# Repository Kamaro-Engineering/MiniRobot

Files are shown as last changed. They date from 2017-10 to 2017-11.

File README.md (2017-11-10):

# MiniRobot
All construction files for a mini robot platform.

This mini robot platform was developed as an entry project for the [KAMARO](https://kamaro-engineering.de/) student group. 

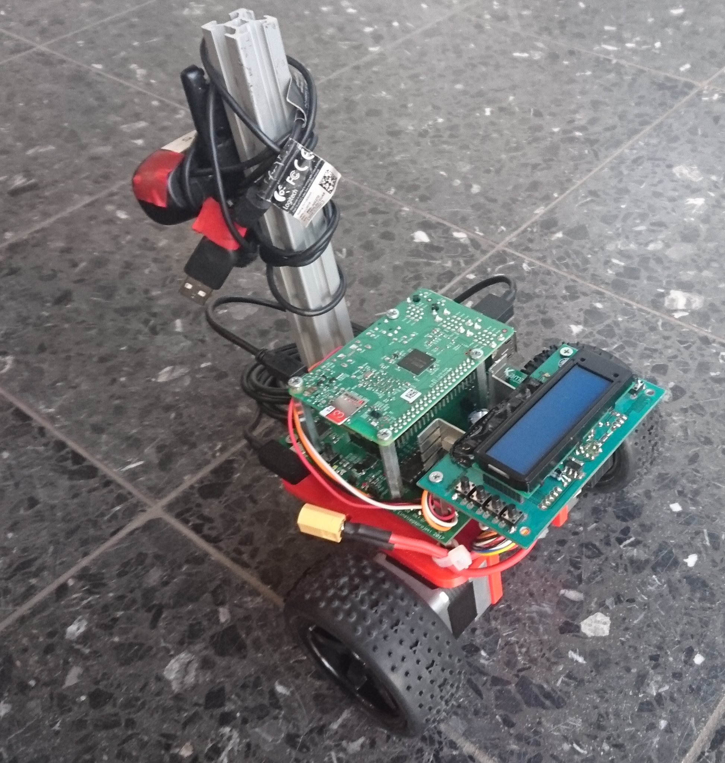
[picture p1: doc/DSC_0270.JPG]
robot

(The display is not part of this project but by chance the drill holes fitted)

# CAD / Mechanics

At the moment we only provide the stl file of the robot base. On request I can provide the Free Cad file too. 

For assembly you need to 3D print the base. We did this on an ultimaker 2+.
The stepper motors we used are standard NEMA12 steppers in combination with standard rc car wheels. (Diameter will be added after I measured it)

# Circuit / Layout

The circuit schematics and layouts were done in the EAGLE layout software. The layout is partly in THT and SMD. All ICs apart from the FTDI (which is only available in SMD) are in THT, the resistors and capacitors are mostly in SMD (0805). As they are in 0805 also beginners will be able to solder them with a bit of training. (It sounds hardware that it is ;) 

The only part you have to adjust are the resistor values for the current limit of the L297. Adapt them to your maximum allowed motor current. (R7,R8 and R3,R4)

The four drill holes in the middle can be used in order to mount a raspberry pi 2 (or 3).

# Software

We provide a fully functional firmware for the Atmega48 (or 88). See the readme in the source subfolder for the serial communication protocol. (It's really simple, just 4 bytes). In most case the only thing you might have to adapt are the constants of the odomotry which is calculated with the amount of steps done by the steppers. For example in case you use a stepper with smaller steps or larger wheels you will have to adapt these constants.

See the [software readme](source/README.md)!

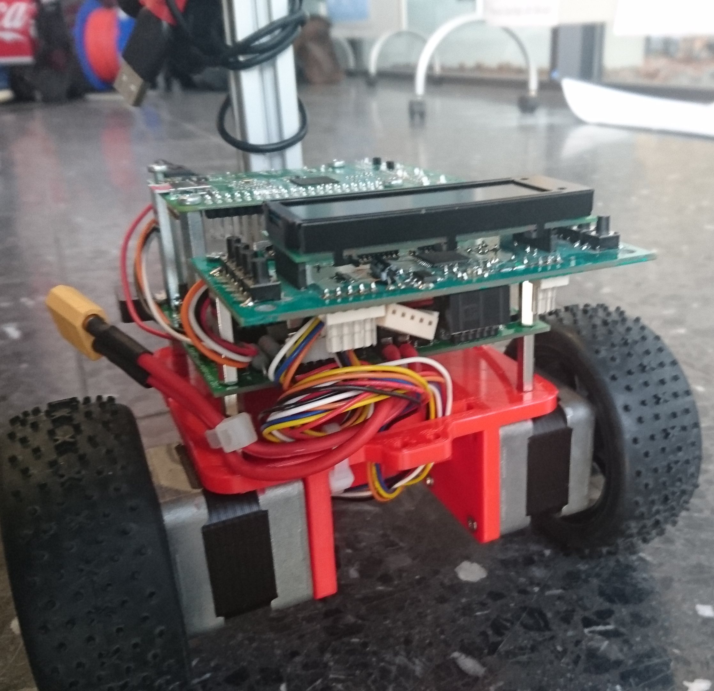
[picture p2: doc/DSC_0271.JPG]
robot1


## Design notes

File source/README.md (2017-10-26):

# MiniRobot - Embeddedcode

This code is written for an Atmega48 (or 88) in C. It can be compiled with avr-gcc.
On Linux you need the following packages:

```
sudo apt install gcc-avr avr-libc  avrdude make
```
In order to build the code, open a terminal, step into the src folder and type `make`.
Via `make program` you can program the controller with a avr-isp mk II programmer. For other programmers have a look at the makefile.

## Communicationprotocol

The robot supports the following commands via a virtual comport. (500000 BAUD)

Format:
STARTBYTE | Command | Highbyte-Data | Lowbyte-Data |

The STARTBYTE matches the ASCII '#'

Commands that can be sent to the robot.

| Command | Data | Description |
| --- | --- | --- |
| 0x01 | enable | Enables/Disables motors  |
| 0x02 | speed left | Set velocity or speed for the left side  (signed integer!)|
| 0x03 | speed right | Set velocity or speed for the right side (signed integer!) |
| 0x04 | led number | Enable LED x |
| 0x05 | led number | Disable LED x |
| 0x06 | PWM | Set pwm freq of fan  |
| 0x07 | PWM | Set pwm freq of external pin | 
| 0x08 | enable | Enable/Disables sending of ultrasonic sensor  data |
| 0x09 | enable | Enable/Disables sending of battery voltage |
| 0x0A | enable | Enable/Disables sending of motor currents |
| 0x0B | enable | Enable/Disables sending of Encoder right and left | 
| 0x0C | enable | Enable/Disables sending of Odometry x,y and phi | 

Data that will be sent back from the robot.

| Command | Data | Description |
| --- | --- | --- |
| 0x80 | ultra sonic sensor distance in cm | ultra sonic sensor |
| 0x81 | Battery voltage in mV |  |
| 0x82 | Motor current left in mA | |
| 0x83 | Motor current right in mA |  |
| 0x84 | Taster pressed |  |
| 0x85 | Encoder right |  |
| 0x86 | Encoder left |  |
| 0x87 | Odometry x |  |
| 0x88 | Odometry y |  |
| 0x89 | Odometry phi |  |

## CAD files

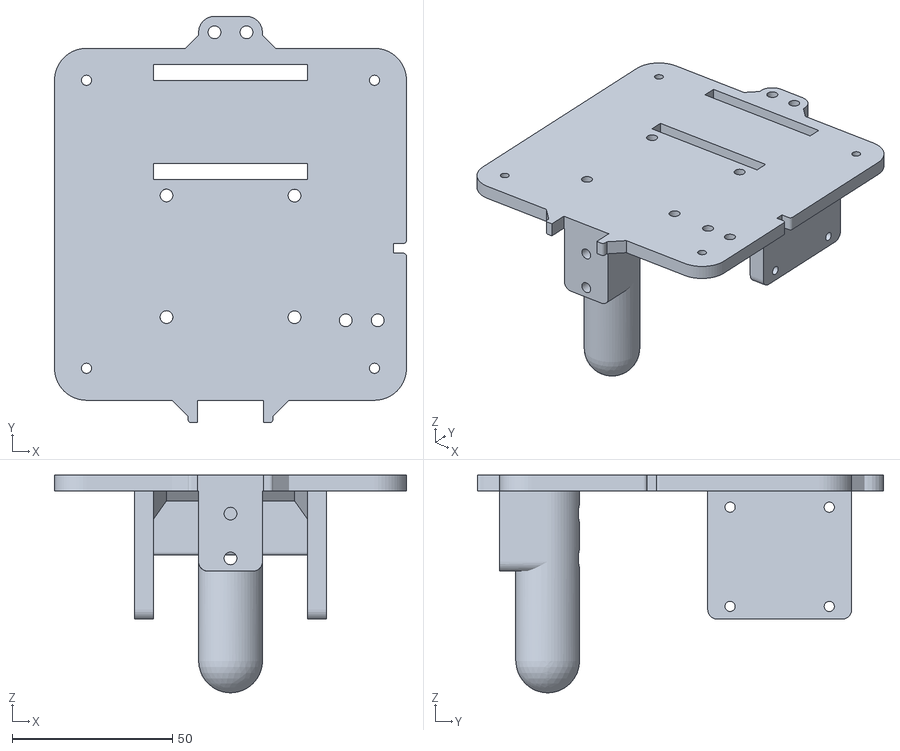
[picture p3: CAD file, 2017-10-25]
cad/einstiegsrobot.stl
110.0 x 127.0 x 68.0

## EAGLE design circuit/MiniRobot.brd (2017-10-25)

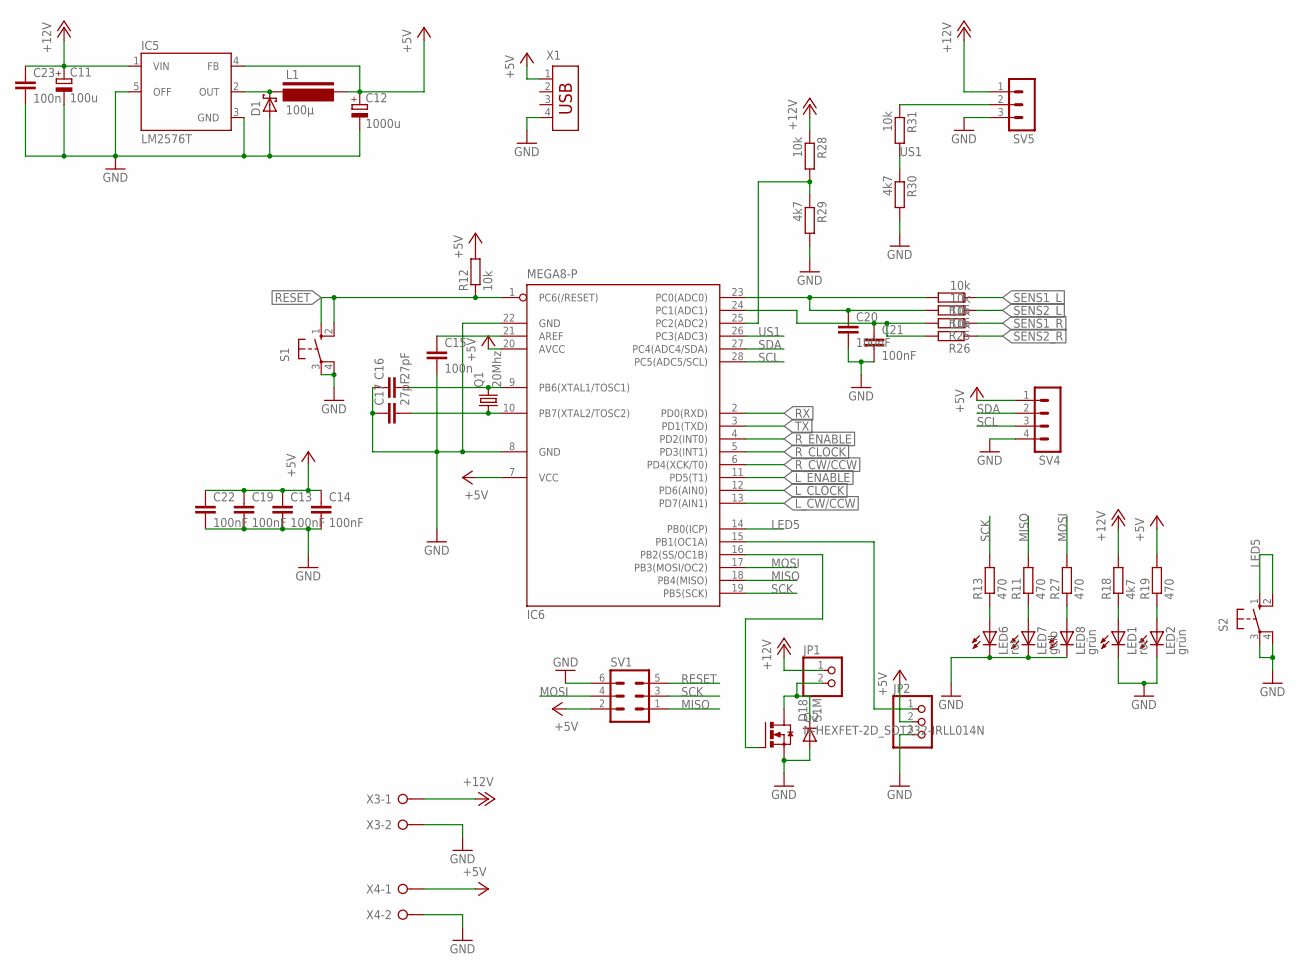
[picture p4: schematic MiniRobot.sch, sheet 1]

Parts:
C11: 100u; E5-10,5
C12: 1000u; E5-10,5
C13, C14, C19, C20, C21, C22: 100nF; C0805
C15, C23: 100n; C0805
C16, C17: 27pF; C0805
D1: SCHOTTKY-DIODEF126Z12; F126Z12
D18: S1M; SMA
IC5: LM2576T; TO220-5
IC6: MEGA8-P; DIL28-3
JP1: PINHD-1X2; 1X02
JP2: PINHD-1X3; 1X03
L1: 100µ; PISR
LED1, LED6: rot; CHIP-LED0805
LED2, LED8: grün; CHIP-LED0805
LED7: gelb; CHIP-LED0805
Q1: 20Mhz; CSM-7X-DU
Q2: N-HEXFET-2D_SOT232-IRLL014N; SOT223
R11, R13, R19: 470; M0805
R12, R15, R31: 10k; R0805
R16, R25, R26, R28: 10k; M0805
R18, R30: 4k7; R0805
R27: 470; R0805
R29: 4k7; M0805
S1, S2: 10-XX; B3F-10XX
SV1: ML6
SV4: MA04-1
SV5: MA03-1
X1: USB-787616; USB
X3, X4: W237-02P; W237-132

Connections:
+5V: C12.+, C13.1, C14.1, C19.1, C22.1, IC5.4 (FB), IC6.7 (VCC), IC6.20 (AVCC), JP2.2, L1.P$2, R12.2, R19.2, SV1.2, SV4.1, X1.1, X4.1; also elsewhere on the board
+12V: C11.+, C23.1, IC5.1 (VIN), JP1.1, R18.2, R28.1, SV5.1, X3.1; also elsewhere on the board
GND: C11.-, C12.-, C13.2, C14.2, C15.2, C16.1, C17.1, C19.2, C20.2, C21.2, C22.2, C23.2, D1.A, D18.A, IC5.3 (GND), IC5.5 (OFF), IC6.8 (GND), IC6.22 (GND), JP2.3, LED1.C, LED2.C, LED6.C, LED7.C, LED8.C, Q2.3 (S), R29.2, R30.2, S1.3, S1.4 (P1), S2.3, S2.4 (P1), SV1.6, SV4.4, SV5.3, X1.4, X3.2, X4.2; also elsewhere on the board
LED5: IC6.14 (PB0(ICP)), S2.1 (S), S2.2 (S1)
L_CLOCK: IC6.12 (PD6(AIN0)); also elsewhere on the board
L_CW/CCW: IC6.13 (PD7(AIN1)); also elsewhere on the board
L_ENABLE: IC6.11 (PD5(T1)); also elsewhere on the board
MISO: IC6.18 (PB4(MISO)), R11.2, SV1.1
MOSI: IC6.17 (PB3(MOSI/OC2)), R27.2, SV1.4
unnamed: LED8.A, R27.1
unnamed: C21.1, IC6.24 (PC1(ADC1)), R25.2, R26.2
unnamed: C15.1, IC6.21 (AREF)
unnamed: C16.2, IC6.9 (PB6(XTAL1/TOSC1)), Q1.2
unnamed: D1.C, IC5.2 (OUT), L1.P$1
unnamed: IC6.25 (PC2(ADC2)), R28.2, R29.1
unnamed: C17.2, IC6.10 (PB7(XTAL2/TOSC2)), Q1.1
unnamed: C20.1, IC6.23 (PC0(ADC0)), R15.2, R16.2
unnamed: LED1.A, R18.1
unnamed: LED2.A, R19.1
unnamed: LED6.A, R13.1
unnamed: LED7.A, R11.1
unnamed: R31.1, SV5.2
unnamed: D18.C, JP1.2, Q2.2 (D), Q2.4 (D)
unnamed: IC6.16 (PB2(SS/OC1B)), Q2.1 (G)
unnamed: IC6.15 (PB1(OC1A)), JP2.1
RESET: IC6.1 (PC6(/RESET)), R12.1, S1.1 (S), S1.2 (S1), SV1.5; also elsewhere on the board
RX: IC6.2 (PD0(RXD)); also elsewhere on the board
R_CLOCK: IC6.5 (PD3(INT1)); also elsewhere on the board
R_CW/CCW: IC6.6 (PD4(XCK/T0)); also elsewhere on the board
R_ENABLE: IC6.4 (PD2(INT0)); also elsewhere on the board
SCK: IC6.19 (PB5(SCK)), R13.2, SV1.3
SCL: IC6.28 (PC5(ADC5/SCL)), SV4.3
SDA: IC6.27 (PC4(ADC4/SDA)), SV4.2
SENS1_L: R15.1; also elsewhere on the board
SENS1_R: R25.1; also elsewhere on the board
SENS2_L: R16.1; also elsewhere on the board
SENS2_R: R26.1; also elsewhere on the board
TX: IC6.3 (PD1(TXD)); also elsewhere on the board
US1: IC6.26 (PC3(ADC3)), R30.1, R31.2

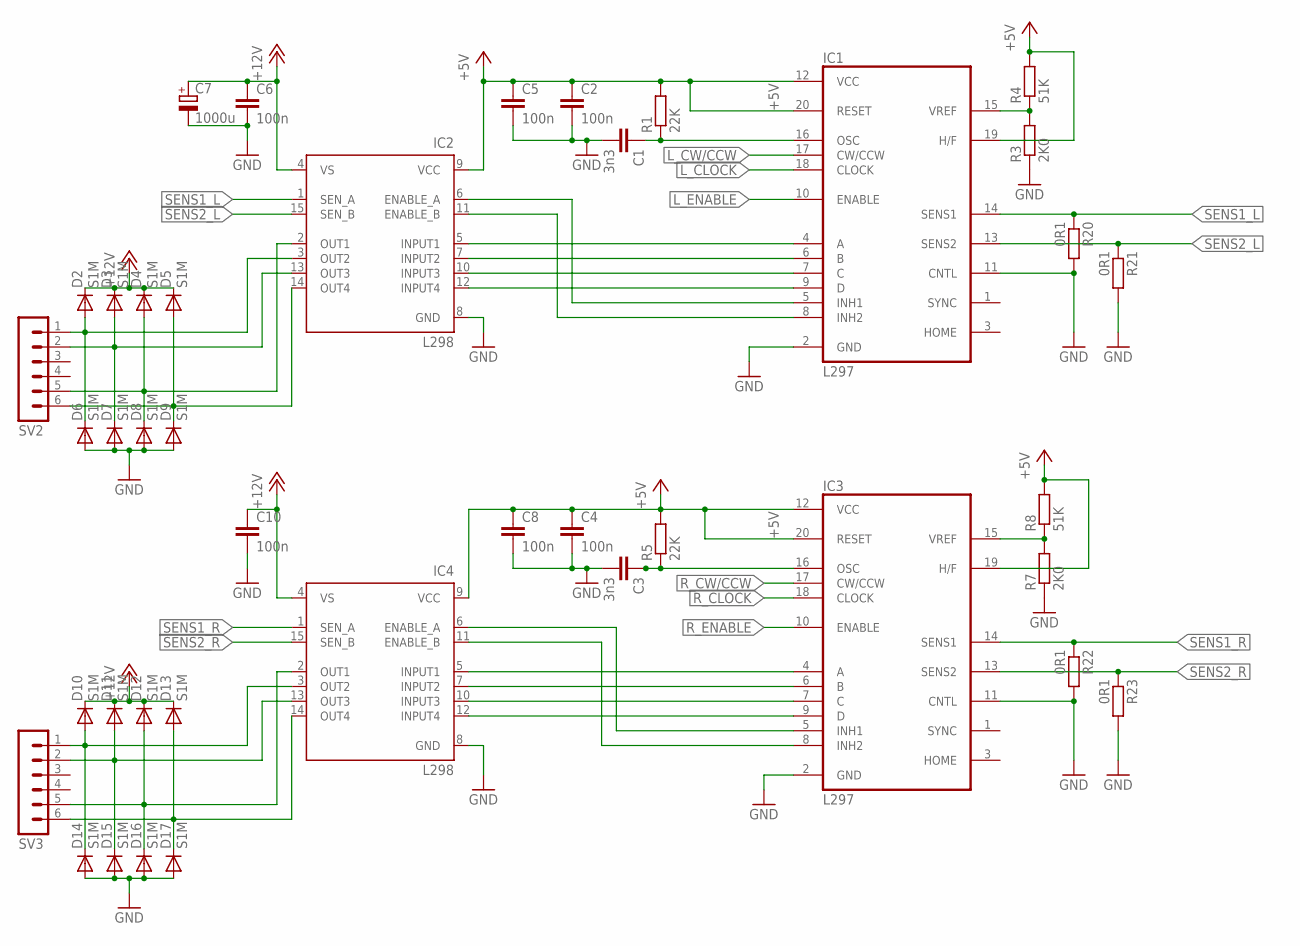
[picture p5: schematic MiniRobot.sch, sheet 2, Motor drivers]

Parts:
C1, C3: 3n3; C0805
C2, C4, C5, C6, C8, C10: 100n; C0805
C7: 1000u; E5-10,5
D2, D3, D4, D5, D6, D7, D8, D9, D10, D11, D12, D13, D14, D15, D16, D17: S1M; SMA
IC1, IC3: L297; DIL20
IC2, IC4: L298; MULTIWATT-15
R1, R5: 22K; R0805
R3, R7: 2K0; R0805
R4, R8: 51K; R0805
R20, R21, R22, R23: 0R1; P0613/15
SV2, SV3: MA06-1

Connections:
+5V: C2.1, C4.1, C5.1, C8.1, IC1.12 (VCC), IC1.19 (H/F), IC1.20 (RESET), IC2.9 (VCC), IC3.12 (VCC), IC3.19 (H/F), IC3.20 (RESET), IC4.9 (VCC), R1.2, R4.2, R5.2, R8.2; also elsewhere on the board
+12V: C6.1, C7.+, C10.1, D2.C, D3.C, D4.C, D5.C, D10.C, D11.C, D12.C, D13.C, IC2.4 (VS), IC4.4 (VS); also elsewhere on the board
GND: C1.2, C2.2, C3.2, C4.2, C5.2, C6.2, C7.-, C8.2, C10.2, D6.A, D7.A, D8.A, D9.A, D14.A, D15.A, D16.A, D17.A, IC1.2 (GND), IC1.11 (CNTL), IC2.8 (GND), IC3.2 (GND), IC3.11 (CNTL), IC4.8 (GND), R3.1, R7.1, R20.2, R21.2, R22.2, R23.2; also elsewhere on the board
L_CLOCK: IC1.18 (CLOCK); also elsewhere on the board
L_CW/CCW: IC1.17 (CW/CCW); also elsewhere on the board
L_ENABLE: IC1.10 (ENABLE); also elsewhere on the board
unnamed: C1.1, IC1.16 (OSC), R1.1
unnamed: IC1.4 (A), IC2.5 (INPUT1)
unnamed: IC1.6 (B), IC2.7 (INPUT2)
unnamed: IC1.7 (C), IC2.10 (INPUT3)
unnamed: C3.1, IC3.16 (OSC), R5.1
unnamed: IC3.6 (B), IC4.7 (INPUT2)
unnamed: IC1.9 (D), IC2.12 (INPUT4)
unnamed: IC1.5 (INH1), IC2.6 (ENABLE_A)
unnamed: IC1.15 (VREF), R3.2, R4.1
unnamed: D4.A, D8.C, IC2.2 (OUT1), SV2.5
unnamed: IC3.4 (A), IC4.5 (INPUT1)
unnamed: IC3.7 (C), IC4.10 (INPUT3)
unnamed: IC3.9 (D), IC4.12 (INPUT4)
unnamed: IC3.15 (VREF), R7.2, R8.1
unnamed: IC3.5 (INH1), IC4.6 (ENABLE_A)
unnamed: IC1.8 (INH2), IC2.11 (ENABLE_B)
unnamed: D2.A, D6.C, IC2.3 (OUT2), SV2.1
unnamed: D3.A, D7.C, IC2.13 (OUT3), SV2.2
unnamed: D5.A, D9.C, IC2.14 (OUT4), SV2.6
unnamed: IC3.8 (INH2), IC4.11 (ENABLE_B)
unnamed: D10.A, D14.C, IC4.3 (OUT2), SV3.1
unnamed: D12.A, D16.C, IC4.2 (OUT1), SV3.5
unnamed: D13.A, D17.C, IC4.14 (OUT4), SV3.6
unnamed: D11.A, D15.C, IC4.13 (OUT3), SV3.2
R_CLOCK: IC3.18 (CLOCK); also elsewhere on the board
R_CW/CCW: IC3.17 (CW/CCW); also elsewhere on the board
R_ENABLE: IC3.10 (ENABLE); also elsewhere on the board
SENS1_L: IC1.14 (SENS1), IC2.1 (SEN_A), R20.1; also elsewhere on the board
SENS1_R: IC3.14 (SENS1), IC4.1 (SEN_A), R22.1; also elsewhere on the board
SENS2_L: IC1.13 (SENS2), IC2.15 (SEN_B), R21.1; also elsewhere on the board
SENS2_R: IC3.13 (SENS2), IC4.15 (SEN_B), R23.1; also elsewhere on the board

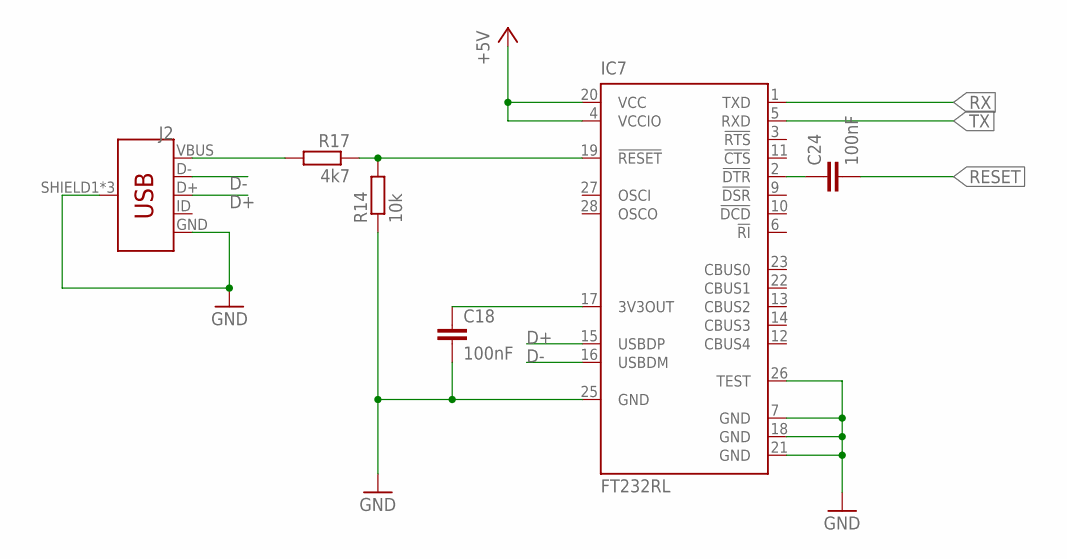
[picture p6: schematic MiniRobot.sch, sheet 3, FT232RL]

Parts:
C18, C24: 100nF; C0805
IC7: FT232RL; SSOP28
J2: USB_MICRO-B_FEMALE-SMT; USB-B-MICRO-SMD
R14: 10k; M0805
R17: 4k7; M0805

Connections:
+5V: IC7.4 (VCCIO), IC7.20 (VCC); also elsewhere on the board
D+: IC7.15 (USBDP), J2.D+
D-: IC7.16 (USBDM), J2.D-
GND: C18.2, IC7.7 (GND), IC7.18 (GND), IC7.21 (GND), IC7.25 (GND), IC7.26 (TEST), J2.GND, J2.SHIELD1 (SHIELD), J2.SHIELD2 (SHIELD), J2.SHIELD3 (SHIELD), R14.1; also elsewhere on the board
unnamed: J2.VBUS, R17.2
unnamed: IC7.19 (!RESET), R14.2, R17.1
unnamed: C18.1, IC7.17 (3V3OUT)
unnamed: C24.1, IC7.2 (!DTR)
RESET: C24.2; also elsewhere on the board
RX: IC7.1 (TXD); also elsewhere on the board
TX: IC7.5 (RXD); also elsewhere on the board

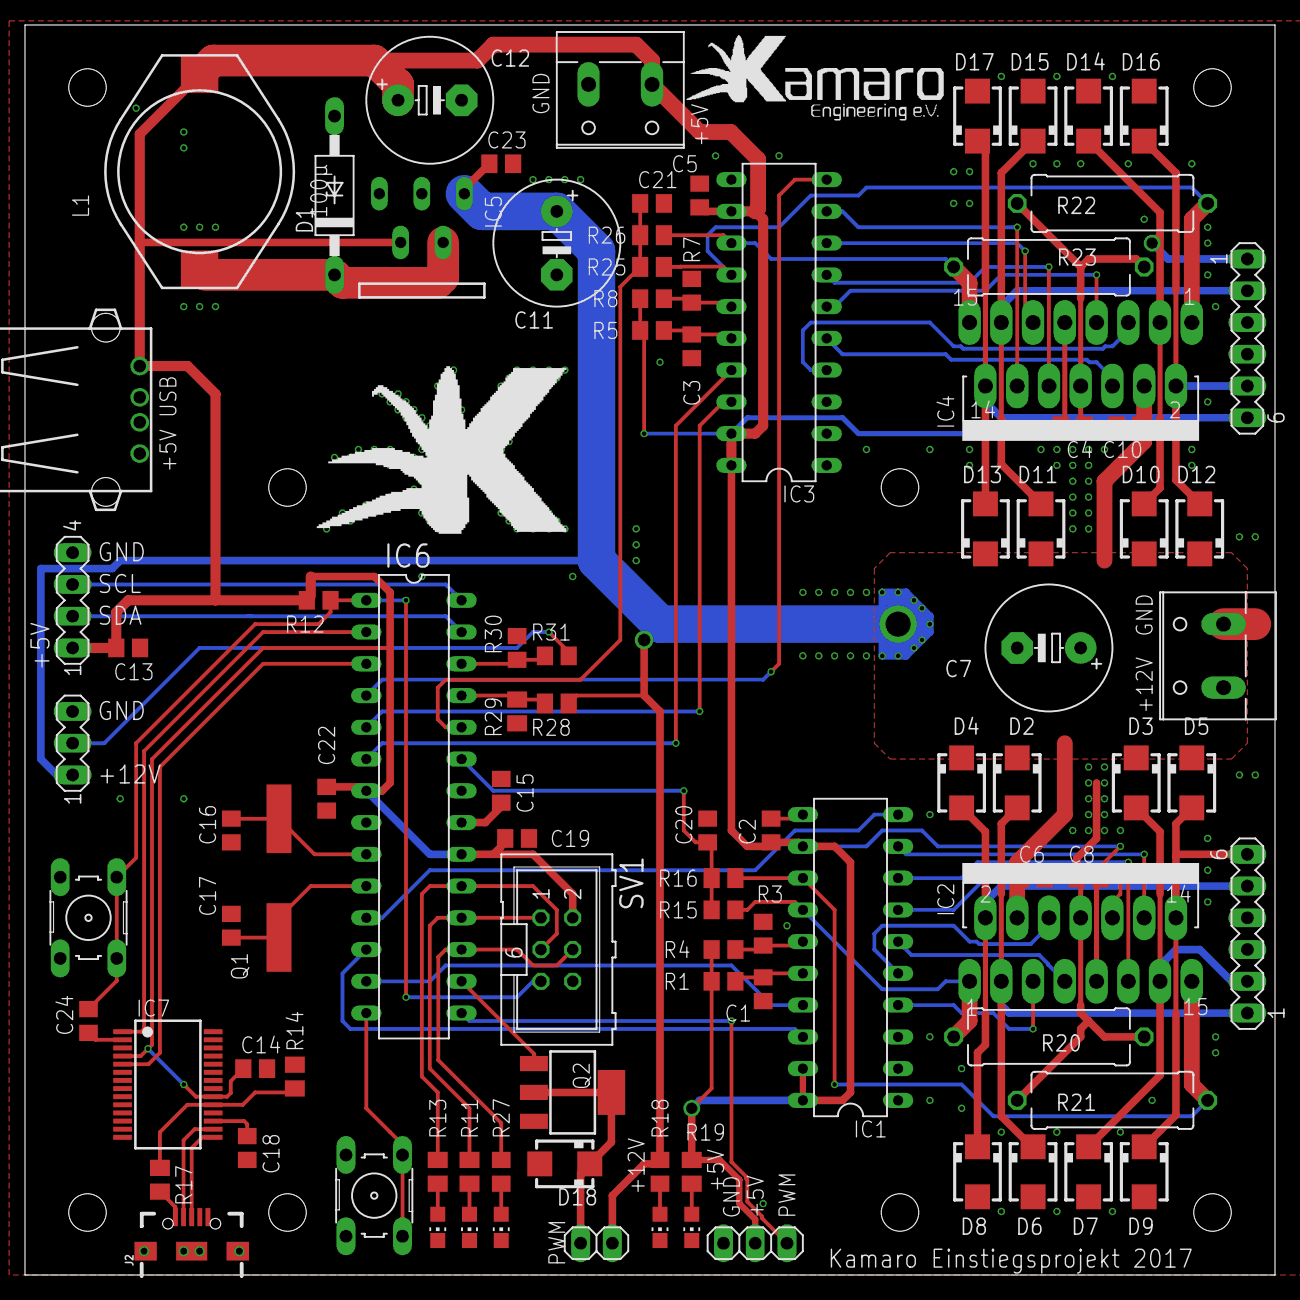
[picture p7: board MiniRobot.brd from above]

Board: 2 copper layers, 100.0 x 100.0 mm, 95 parts (0 on the bottom side), 69 nets.

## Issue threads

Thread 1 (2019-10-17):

Wrong Value for L297 sense resistors in schematic.

knicklux, 2019-10-17:
Wrong Value for L297 sense resistors in schematic.

The correct value according to the L297 datasheet and our measurements on the existing board is 0.5 Ohm. The value in the schematic is 0.1 Ohm.

firesurfer, 2019-10-18:
So einfach ist das nicht ;) Frag mal Frodo auf Signal deswegen hab heute
keine Zeit da reinzuschauen

Nicolas Kessler <notifications@github.com> schrieb am Do., 17. Okt. 2019,
22:59:

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

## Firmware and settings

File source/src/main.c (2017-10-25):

/*
 * Copyright 2017 <Lennart Nachtigall, Friedolin Gröger> <firesurfer127@gmail.com, gfrodo@gmx.de>
 *
 * Licensed under the Apache License, Version 2.0 (the "License");
 * you may not use this file except in compliance with the License.
 * You may obtain a copy of the License at
 *
 *     http://www.apache.org/licenses/LICENSE-2.0
 *
 * Unless required by applicable law or agreed to in writing, software
 * distributed under the License is distributed on an "AS IS" BASIS,
 * WITHOUT WARRANTIES OR CONDITIONS OF ANY KIND, either express or implied.
 * See the License for the specific language governing permissions and
 * limitations under the License.
 *
 */


#include <stdlib.h>
#include <avr/io.h>
#include <avr/interrupt.h>
#include <util/delay.h>
#define UART_BAUD_RATE 500000

#include "uart_parser.h"
#include "motor.h"
#include "odom.h"
#include "i2cmaster.h"
#include "adc.h"
#include "pwm.h"
#include "pins.h"

struct {
    uint8_t send_battery_voltage : 1;
    uint8_t send_ultra_sonic_data : 1;
    uint8_t send_motor_currents : 1;
    uint8_t send_encoders : 1;
    uint8_t send_odometry : 1;
} flags;


void handle_commands(uint8_t command, uint16_t data)
{
    switch (command) {
    case 0x01:
        set_motor_enable(data);
        break;
    case 0x02:
        motor_speed_l(data);
        set_motor_enable_l(data?1:0);
        break;
    case 0x03:
        motor_speed_r(data);
        set_motor_enable_r(data?1:0);
        break;
    case 0x04://set LED x
        if (data == 0)
            LED_ON(LED1_bm);
        if (data == 1)
            LED_ON(LED2_bm);
        if (data == 2)
            LED_ON(LED3_bm);
        break;
    case 0x05://clear LED x
        if (data == 0)
            LED_OFF(LED1_bm);
        if (data == 1)
            LED_OFF(LED2_bm);
        if (data == 2)
            LED_OFF(LED3_bm);
        break;
    case 0x06://Set fan PWM
        set_PWM(data);
        break;
    case 0x07://Set external PWM
        set_servo(data);
        break;
    case 0x08:
        flags.send_ultra_sonic_data = data;
        break;
    case 0x09:
        flags.send_battery_voltage = data;
        break;
    case 0x0A:
        flags.send_motor_currents = data;
        break;
    case 0x0B:
        flags.send_encoders = data;
        break;
    case 0x0C:
        flags.send_odometry = data;
        break;

    }
}

int main(void)
{
    //enable UART
    uart_init(UART_BAUD_SELECT_DOUBLE_SPEED(UART_BAUD_RATE, F_CPU));
    //Init parser for uart commands
    init_parser();
    //register functions ptr for command handler
    set_command_handler(handle_commands);

    motor_init();
    adc_init();
    reset_odom();
    //i2c_init();
    PORTI2C = SCL_bm | SDA_bm; //Enable Pullups for I2C

    DDRIO = LED1_bm | LED2_bm | LED3_bm | PWM_bm | SERVO_bm; //Configure LEDs and PWM as outputs
    PORTIO = TASTER_bm; //activate pullup

    pwm_init();

    //enable interrupts
    sei();

    uart_puts("Hello world");

    int16_t encoder_r = 0;
    int16_t encoder_l = 0;
    uint8_t taster_pressed = 0;
    while (1) {
        encoder_r = get_odom_r();
        encoder_l = get_odom_l();
        update_odom(encoder_r, encoder_l);
        if (taster_pressed && !PRESSED(TASTER_bm)) {
            taster_pressed = 0;
            send_command(0x84, 1);
        }
        if (!taster_pressed && PRESSED(TASTER_bm)) {
            taster_pressed = 1;
            send_command(0x84, 0);
        }
        if (flags.send_battery_voltage) {
            uint16_t bat = adc_value(2);
            send_command(0x81,  bat);
        }
        if (flags.send_motor_currents) {
            uint16_t left = adc_value(0);
            uint16_t right = adc_value(1);

            send_command(0x82, left);
            send_command(0x83, right);
        }
        if (flags.send_ultra_sonic_data) {
            uint16_t ultra_sonic = adc_value(3);
            send_command(0x80, ultra_sonic);
        }
        if (flags.send_encoders) {
            send_command(0x85, encoder_r);
            send_command(0x86, encoder_l);
        }
        if (flags.send_odometry) {
            send_command(0x87, get_odom_x());
            send_command(0x88, get_odom_y());
            send_command(0x89, get_odom_phi());
        }
        _delay_ms(100);
        //LED_TGL(LED2_bm);
    }
    return 0;
}

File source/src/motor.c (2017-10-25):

/*
 * Copyright 2017 <Lennart Nachtigall, Friedolin Gröger> <firesurfer127@gmail.com, gfrodo@gmx.de>
 *
 * Licensed under the Apache License, Version 2.0 (the "License");
 * you may not use this file except in compliance with the License.
 * You may obtain a copy of the License at
 *
 *     http://www.apache.org/licenses/LICENSE-2.0
 *
 * Unless required by applicable law or agreed to in writing, software
 * distributed under the License is distributed on an "AS IS" BASIS,
 * WITHOUT WARRANTIES OR CONDITIONS OF ANY KIND, either express or implied.
 * See the License for the specific language governing permissions and
 * limitations under the License.
 *
 */


#include <avr/io.h>
#include <avr/interrupt.h>
#include "motor.h"

#define PIN_R_ENABLE 2
#define PIN_R_CLOCK  3
#define PIN_R_DIR    4
#define PIN_L_ENABLE 5
#define PIN_L_CLOCK  6
#define PIN_L_DIR    7

#define PORTMOT PORTD
#define PINMOT  PIND
#define DDRMOT  DDRD

// To invert direction if one motor is going backwards
#define DIR_INV_R 0
#define DIR_INV_L 0


uint16_t count_r = 0;
uint16_t count_l = 0;

int16_t speed_r = 0;
int16_t speed_l = 0;

volatile int16_t odom_r = 0;
volatile int16_t odom_l = 0;

void set_motor_enable(uint8_t enable)
{
    if (enable)
        PORTMOT |= (1 << PIN_R_ENABLE) | (1 << PIN_L_ENABLE);
    else
        PORTMOT &= ~(1 << PIN_R_ENABLE) & ~(1 << PIN_L_ENABLE);
}
void set_motor_enable_r(uint8_t enable)
{
    if (enable)
        PORTMOT |= (1 << PIN_R_ENABLE) ;
    else
        PORTMOT &= ~(1 << PIN_R_ENABLE) ;
}
void set_motor_enable_l(uint8_t enable)
{
    if (enable)
        PORTMOT |= (1 << PIN_L_ENABLE);
    else
        PORTMOT &= ~(1 << PIN_L_ENABLE);
}

void motor_init()
{
    TCCR0B = (1 << CS01) | (1 << CS00); // Prescaler 64
    TIMSK0 = (1 << TOIE0);            // Overflow interrupt enable
    //TCCR2B = (1<<CS22);               // Prescaler 64
    //TIMSK2 = (1<<TOIE2);              // Overflow interrupt enable
    DDRMOT |= (1 << PIN_R_ENABLE) | (1 << PIN_R_CLOCK) | (1 << PIN_R_DIR)
              | (1 << PIN_L_ENABLE) | (1 << PIN_L_CLOCK) | (1 << PIN_L_DIR);
    //PORTMOT |= (1 << PIN_R_ENABLE) | (1 << PIN_L_ENABLE);
}

void motor_speed_l(int16_t speed)
{
    speed_l = speed;
}
void motor_speed_r(int16_t speed)
{
    speed_r = speed;
}
int16_t get_odom_r()
{
    return odom_r;
}
int16_t get_odom_l()
{
    return odom_l;
}

ISR(TIMER0_OVF_vect)
{
    count_r += abs(speed_r);
    if (count_r & 0x8000) { //on "overflow"
        count_r &= 0x7FFF; //do the overflow
        if (speed_r > 0) {
            odom_r += 1; //count ticks
            if (DIR_INV_R) PORTMOT &= ~(1 << PIN_R_DIR); //set direction pin
            else PORTMOT |= (1 << PIN_R_DIR);
        } else {
            odom_r -= 1;
            if (DIR_INV_R) PORTMOT |= (1 << PIN_R_DIR);
            else PORTMOT &= ~(1 << PIN_R_DIR);
        }
        PINMOT = (1 << PIN_R_CLOCK); //toggle frequency pin
    }
    count_l += abs(speed_l);
    if (count_l & 0x8000) { //on "overflow"
        count_l &= 0x7FFF; //do the overflow
        if (speed_l > 0) {
            odom_l += 1; //count ticks
            if (DIR_INV_L) PORTMOT &= ~(1 << PIN_L_DIR); //set direction pin
            else PORTMOT |= (1 << PIN_L_DIR);
        } else {
            odom_l -= 1;
            if (DIR_INV_L) PORTMOT |= (1 << PIN_L_DIR);
            else PORTMOT &= ~(1 << PIN_L_DIR);
        }
        PINMOT = (1 << PIN_L_CLOCK); //toggle frequency pin
    }
}

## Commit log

2017-10-25 added cad file
    [einstiegsrobot.stl]
2017-10-25 added schematic and layout of board
    [Verteiler.brd, Verteiler.sch]
2017-10-26 moved circuit schematics into folder. updated readme
    [MiniRobot.brd, MiniRobot.sch]

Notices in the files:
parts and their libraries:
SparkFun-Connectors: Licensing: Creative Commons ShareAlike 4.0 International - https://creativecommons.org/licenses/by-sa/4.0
